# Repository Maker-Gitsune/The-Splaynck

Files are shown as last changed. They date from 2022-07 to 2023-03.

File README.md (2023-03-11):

# The Splaynck
My first foray into the world of mechanical keyboards.
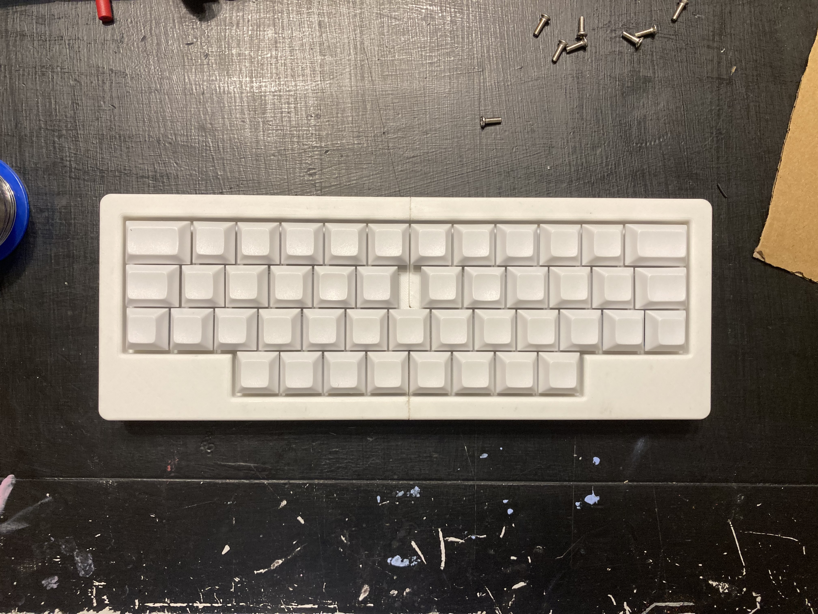
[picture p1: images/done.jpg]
the finished keyboard

# What is it?
banana for scale
- A compact, ergonomic keyboard for a lowish price. (~$50. including components in bulk, about $73 excluding filament.)
- Powered by [KMK](https://github.com/KMKfw/kmk_firmware) and compatible with [Peg](https://peg.software/)
- inspired by the Katana60 and the SICK-68.
# When is it?
- Now.
  - *Starting now. Total time is ~25 hours: ~16h printing, ~8 soldering (at least for me).
# Why is it?
- A ortholinear/grid layout is the most efficient in terms of space, but forces the wrists to bend outwards (uncomfortable).
- Splaying the rows outwards encourages neutral/reduced wrist angle which is more comfortable.
# How?
- The case is 3d printed and electronics are handwired/soldered.
- Everything else can be from Amazon.
- The parts I used/were bought (prices at time of purchase): 
  - [Akko ocean blue switches](https://www.amazon.com/dp/B08XX7TTZB/) - $14
    - 45x of any Cherry MX compatable switch will work.
  - [1N4148 diodes](https://www.amazon.com/dp/B06XB1R2NK) - $5
  - [Raspberry Pi Pico](https://www.amazon.com/dp/B08TVF499B/) - $8
  - [28 AWG wire](https://www.amazon.com/dp/B01F8PO7UK/) - $6
  - [M3 threaded inserts](https://www.amazon.com/dp/B09MCW7ZN5/) - $8
  - [M3x8 FHCS](https://www.amazon.com/dp/B01D4VHJJ6/) - $7.58
  - [YMDK DSA blanks](https://amazon.com/dp/B08YR6KNX9/) - $23
    - exact keycap sizes used:
      | size | Quantity |
      | ------------- | ------------- |
      | 1u    | 41 |
      | 1.25u | 2  |
      | 1.5u  | 2  |
    - It is possible to use all 1u keycaps. Just print the top pieces with "ortho" in the file names.

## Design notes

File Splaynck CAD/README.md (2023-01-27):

# Part orientation/print settings
## Pi Pico holder
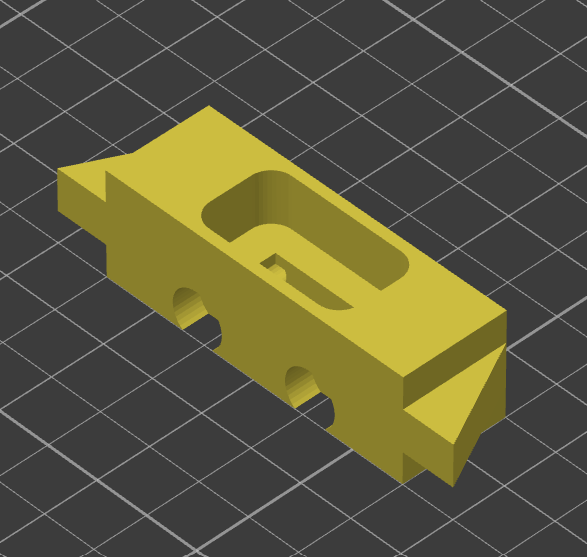
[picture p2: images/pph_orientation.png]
pph orientation

- The rectangle with rounded corners needs to face upwards.
- 3 walls, 3 perimeters, no more than 15% infill, supports enabled.
## Pins
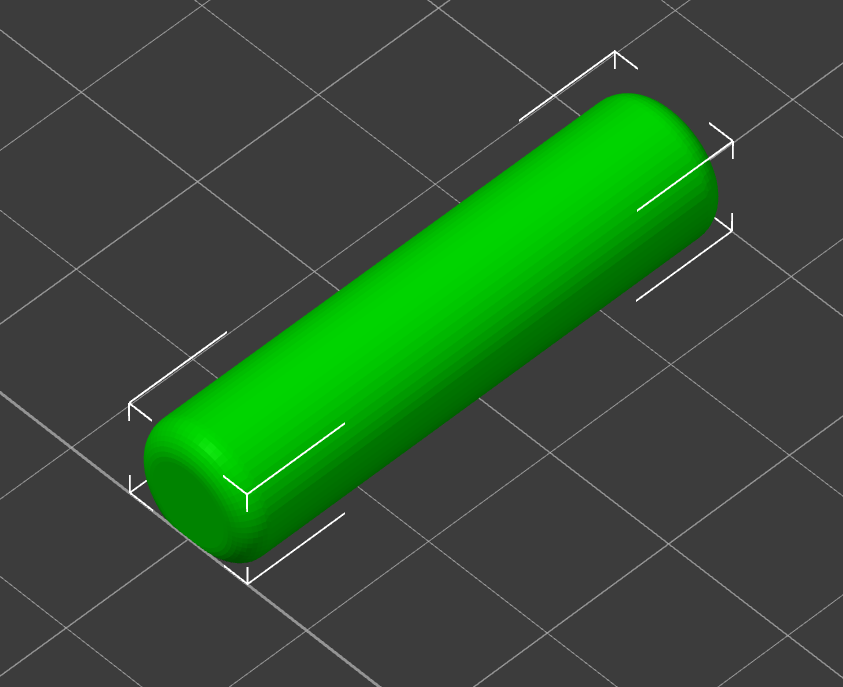
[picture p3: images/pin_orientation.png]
pin orientation

- Print flat side down.
- 3 walls, 2 perimeters, no more than 10% infill
## Tops and bottoms
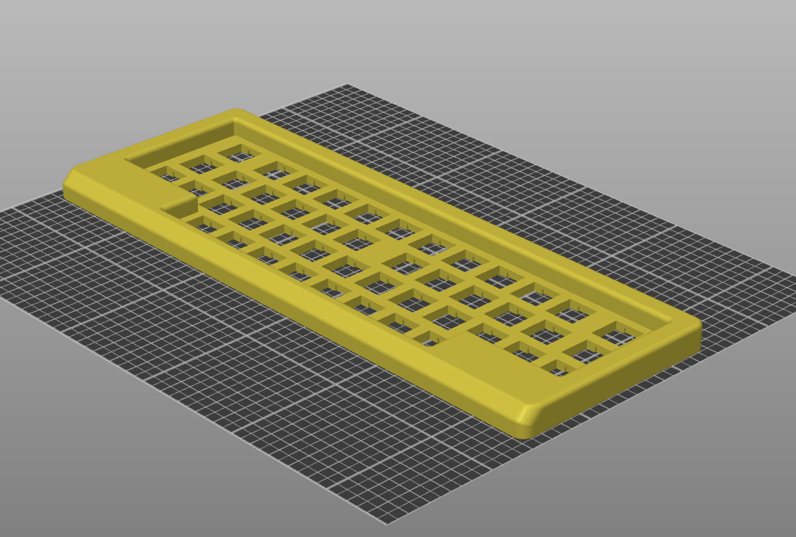
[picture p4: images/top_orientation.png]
top orientation

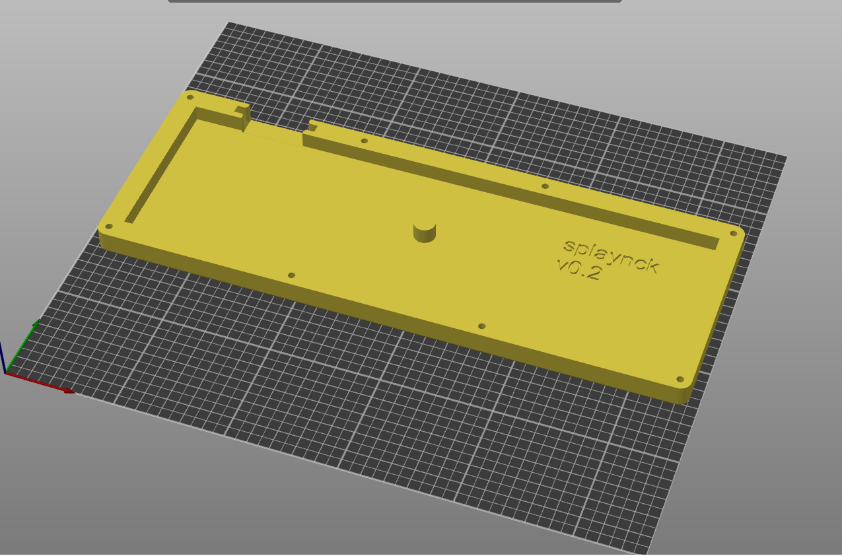
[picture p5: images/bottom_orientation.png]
bottom orientation

- print with largest face down.
- 3 walls, 3 perimeters, no more than 15% infill.

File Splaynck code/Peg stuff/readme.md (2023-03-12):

**IMPORTANT**

Currently, Peg appears to support a limited number of modules/extensions; If you are considering this, reference the Peg-specific main.py to see which are supported.

The code provided is the bare minimum needed to use Peg. If you choose this option, you will need to configure the keymap yourself.

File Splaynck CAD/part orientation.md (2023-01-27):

#Part orientation
- Pi Pico holder
  - The rectangle with rounded corners needs to face upwards.
- Pins
  - Print flat side down.
- Tops and bottoms
  - print with largest face down

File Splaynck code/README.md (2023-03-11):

# Keymap of the provided firmware
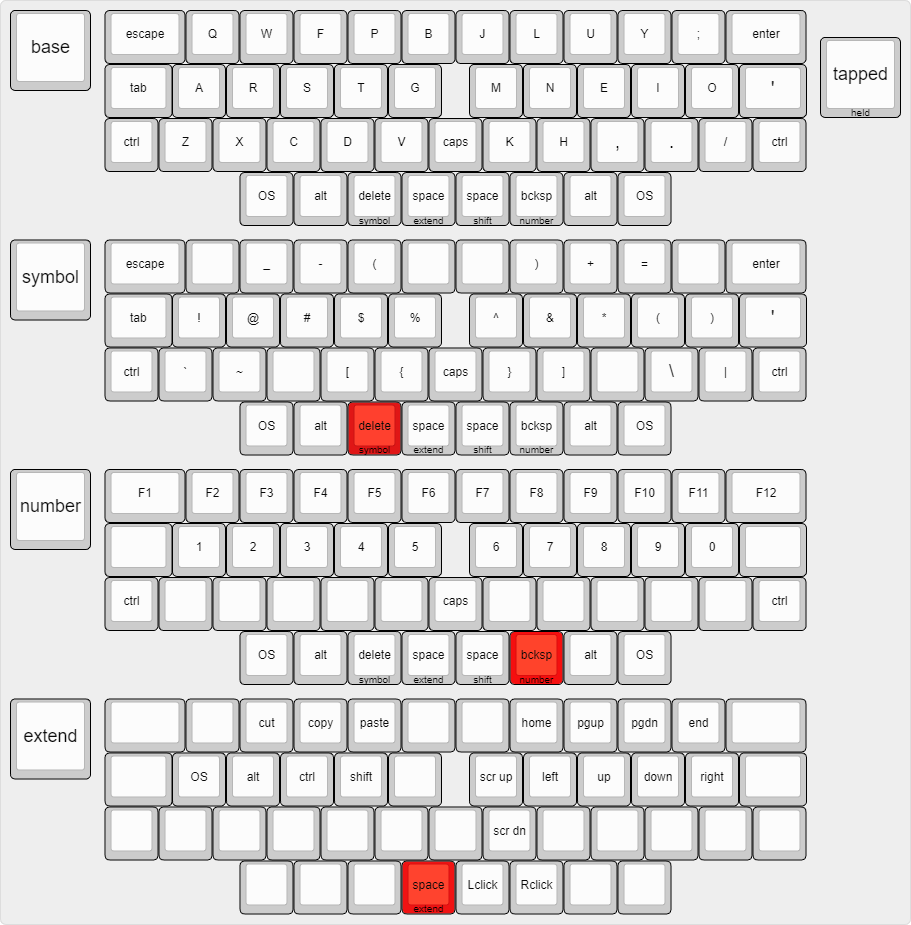
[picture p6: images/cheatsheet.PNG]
keymap


The following chords are not pictured, but are enabled by default:
- W and F send "wh"
- F and P send "ph"
- C and D send "ch"
- G and T send "gh"
- S and the left spacebar send "sh"
- T and the left spacebar send "th"
- Q and the left spacebar send "q"
    - also, "Q" sends "qu"
# Peg support (added 03/11/2023)
**IMPORTANT**
 - Currently, Peg appears to support a limited number of modules/extensions; If you are considering this, reference the Peg-specific main.py to see which are supported.

The code provided is the bare minimum needed to use Peg. If you choose this option, you will need to configure the keymap yourself.

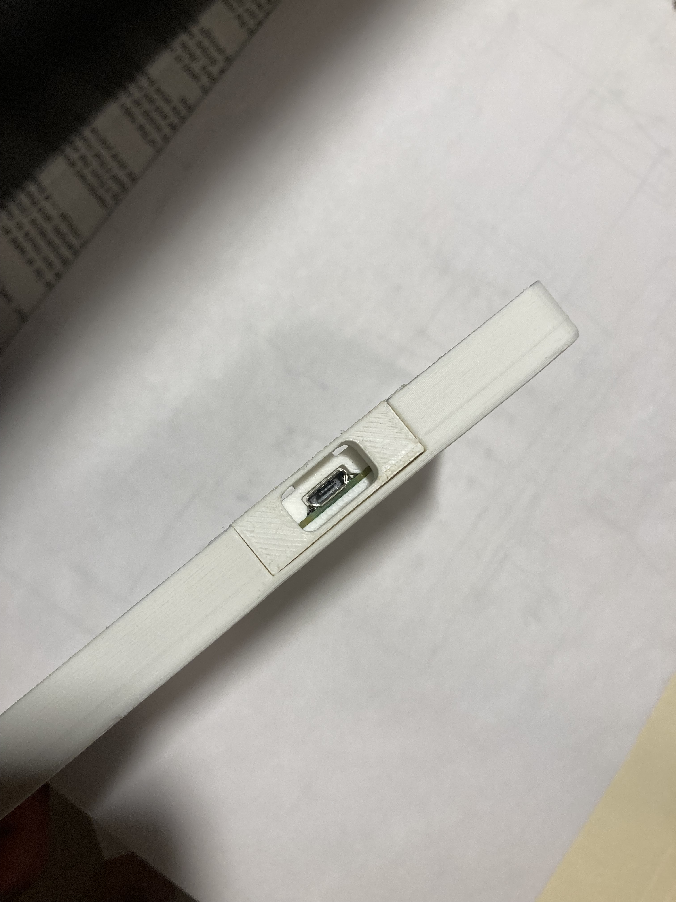
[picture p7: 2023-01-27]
images/pico_usb_port.jpg

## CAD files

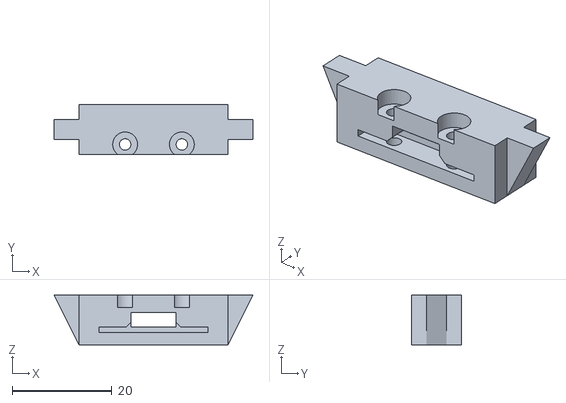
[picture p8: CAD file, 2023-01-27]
Splaynck CAD/pi pico holder.stl
40.0 x 10.0 x 10.0

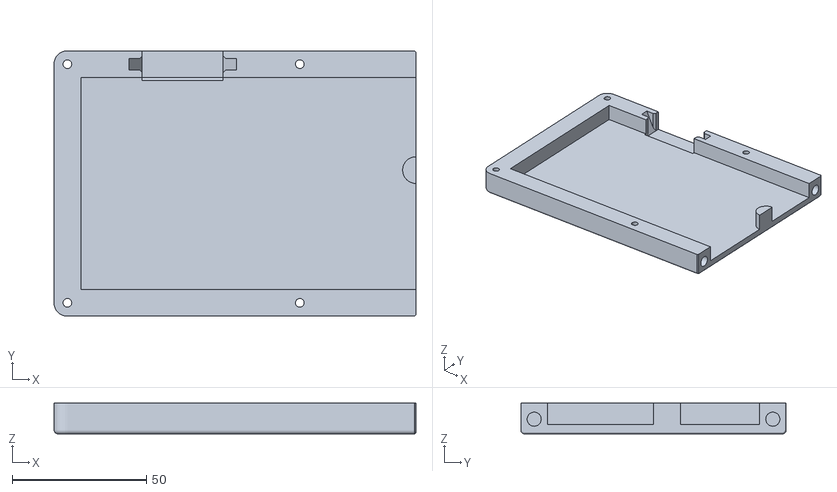
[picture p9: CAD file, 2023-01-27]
Splaynck CAD/splaynck_bottom/splaynck bottom_l.stl
135.0 x 99.0 x 11.5

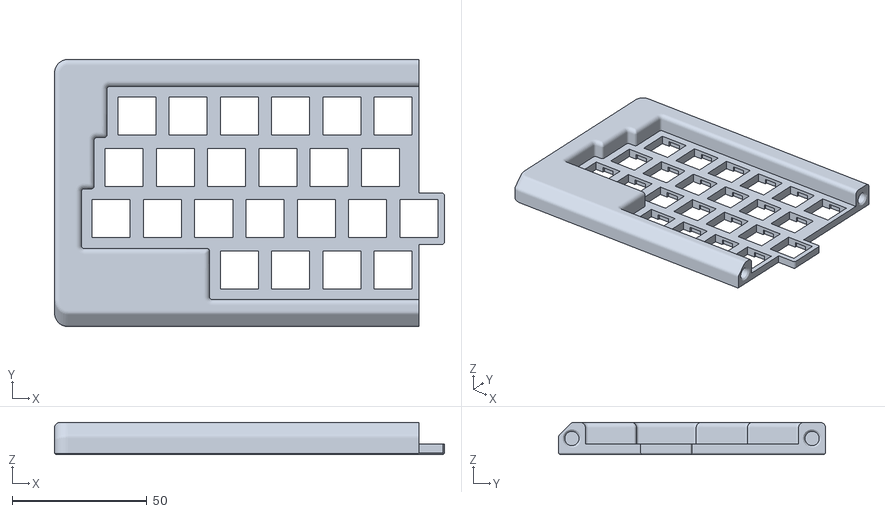
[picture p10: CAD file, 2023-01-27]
Splaynck CAD/splaynck_top/splaynck_ortho_top_l.stl
144.5 x 99.0 x 12.0

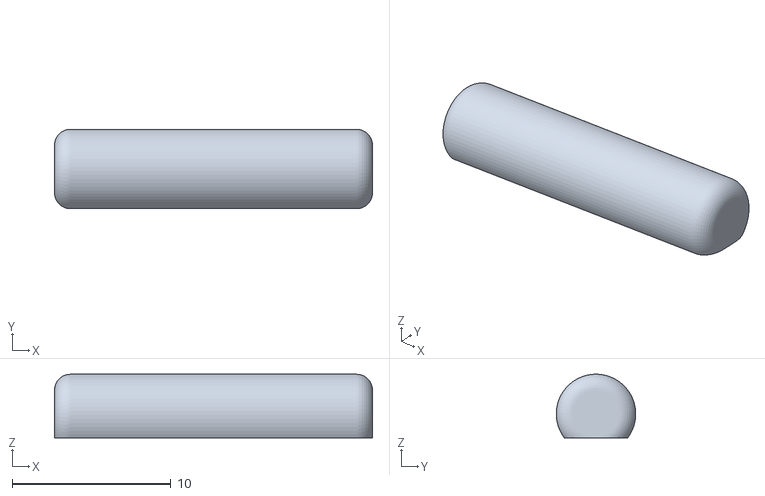
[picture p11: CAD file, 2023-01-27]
Splaynck CAD/splaynck pin.stl
20.0 x 5.00 x 4.00

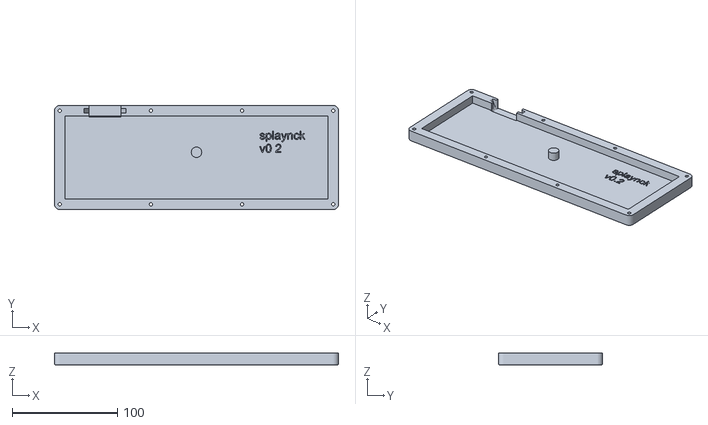
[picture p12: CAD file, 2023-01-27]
Splaynck CAD/splaynck_bottom/splaynck bottom.stl
270.0 x 99.0 x 11.5

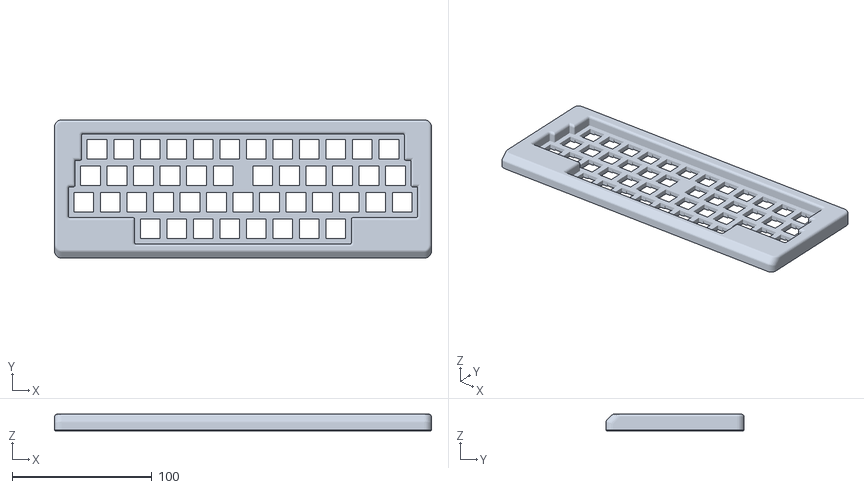
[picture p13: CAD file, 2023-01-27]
Splaynck CAD/splaynck_top/splaynck_ortho_top.stl
270.0 x 99.0 x 12.0

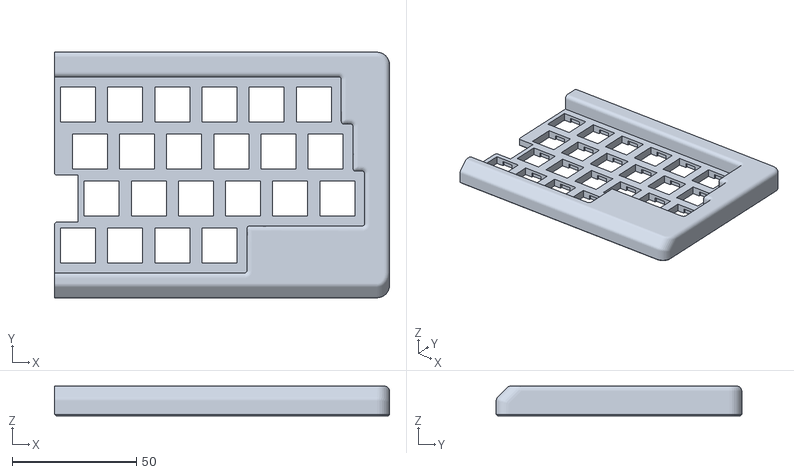
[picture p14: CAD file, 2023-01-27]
Splaynck CAD/splaynck_top/splaynck_ortho_top_r.stl
135.0 x 99.0 x 12.0

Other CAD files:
Splaynck CAD/splaynck_top/splaynck_HHKB_top_l.stl
Splaynck CAD/splaynck_bottom/splaynck bottom_r.stl
Splaynck CAD/splaynck_top/splaynck_HHKB_top_r.stl
Splaynck CAD/splaynck_top/splaynck_HHKB_top.stl

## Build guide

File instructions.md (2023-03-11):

# Prerequisites
- You know how to solder.
- You have installed [Peg](https://peg.software/) if you plan to use it.
# Parts needed
- 45 Cherry MX or compatible switches
- 1N4148 diodes
- Raspberry Pi Pico
- 28 AWG wire
- M3 threaded inserts
- M3x8 FHCS
- A micro USB cable (I used an old phone charger)
- Keycaps
    - exact keycap sizes used:
      | size | Quantity |
      | ------------- | ------------- |
      | 1u    | 41 |
      | 1.25u | 2  |
      | 1.5u  | 2  |
    - It is possible to use all 1u keycaps. Just print the top pieces with "ortho" in the file names.

# Instructions
1. Print one of “top” and “bottom” and the pi pico holder.
    - If you have a smaller print bed (less than 280mm x/y, but equal to or larger than 150mm x/y), print one of top_l, top_r, bottom_l, bottom_r, in addition to 4x pins instead of "top" and "bottom"
    - There are two variations of the top: one with a HHKB-inspired layout and one that is for ortholinear (all 1u) keycap sets.
2. If you haven't, set up and test [KMK](https://github.com/KMKfw/kmk_firmware/blob/master/docs/Getting_Started.md) on the Raspberry Pi Pico you intend to use. Also, make sure your computer has a text editor that supports circuitpython with a serial window. I used [Mu](https://codewith.mu/).
3. If applicable, glue top_l, to top_r, and bottom_l to bottom_r together using the pins.
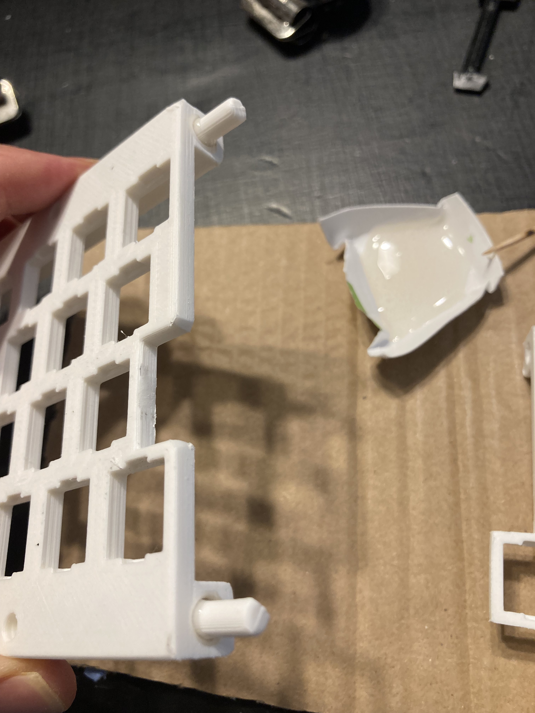
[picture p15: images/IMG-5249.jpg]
pin detail

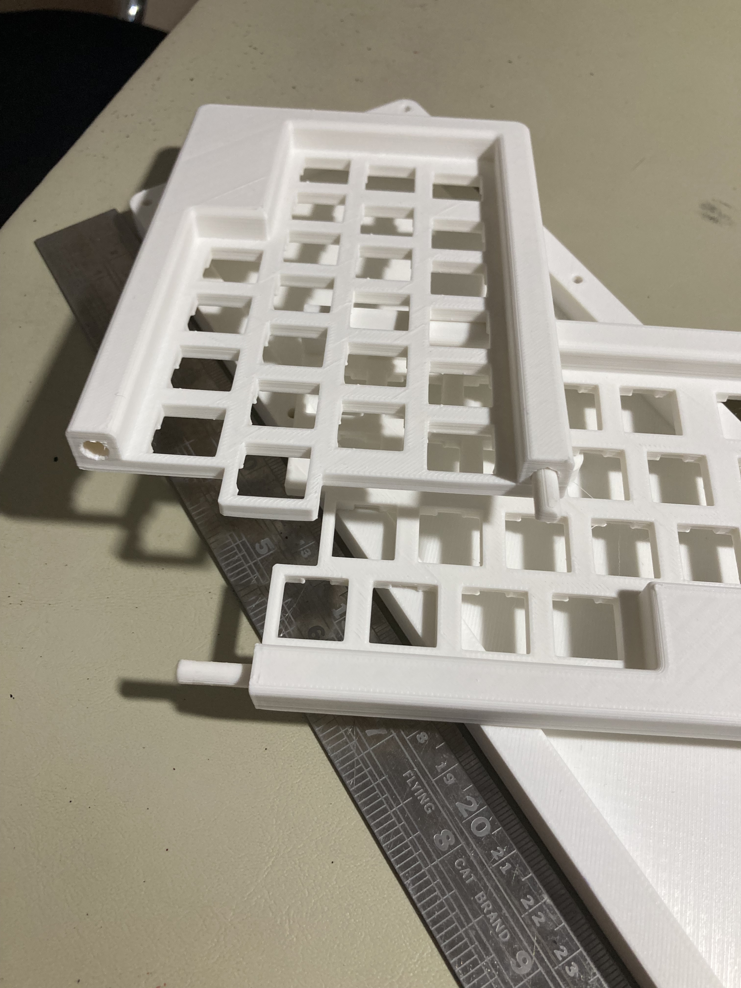
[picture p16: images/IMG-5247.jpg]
pin detail again
 
    - Sanding where the parts come together is recommended for fit and bond strength.
    - If needed, use a box cutter to deburr the holes/edges.
    - Feel free to sand the outside once the glue is cured.
4. Add heat set inserts to the 8 holes in “top”
5. Install switches with the LED slots at the bottom
6. insert the Pi Pico into the holder, and the holder into the bottom. Note that the Pi Pico will only go in one way.
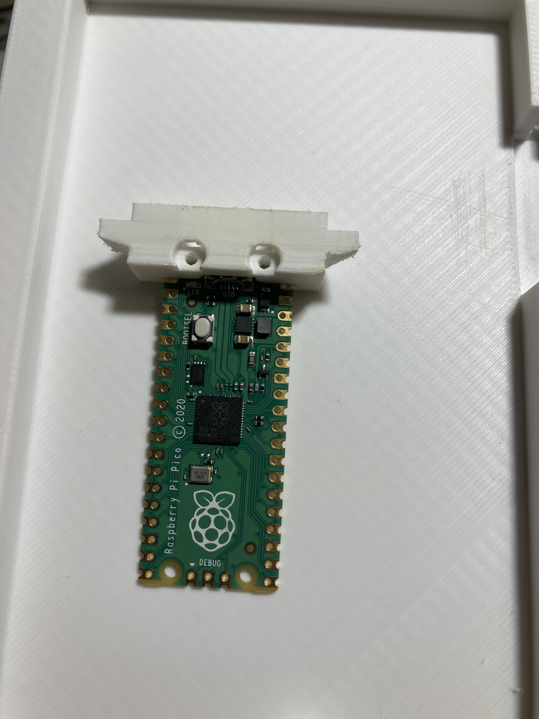
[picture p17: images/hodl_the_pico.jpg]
pico holder

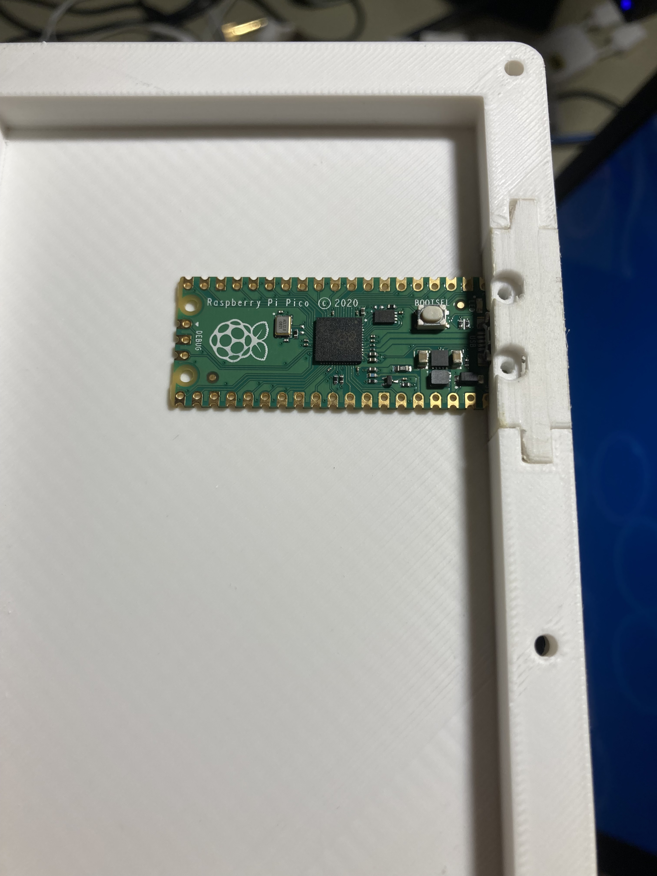
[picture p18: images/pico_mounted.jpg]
mounted

    - It is optional, but hightly reccomended that the Pi Pico is fastened to the insert by the use of pins made of short lengths of 1.75mm filament. You will likely need to ream the holes in the holder with a 2mm drill bit before the filament will fit. Make sure that the filament is cut flush with the top of the holder.
    - The bottom corners will likely need some sanding.
7. Handwire according to the pictures below. Make sure the wires are long enough to reach the pi when both halves' front halves when they are touching.
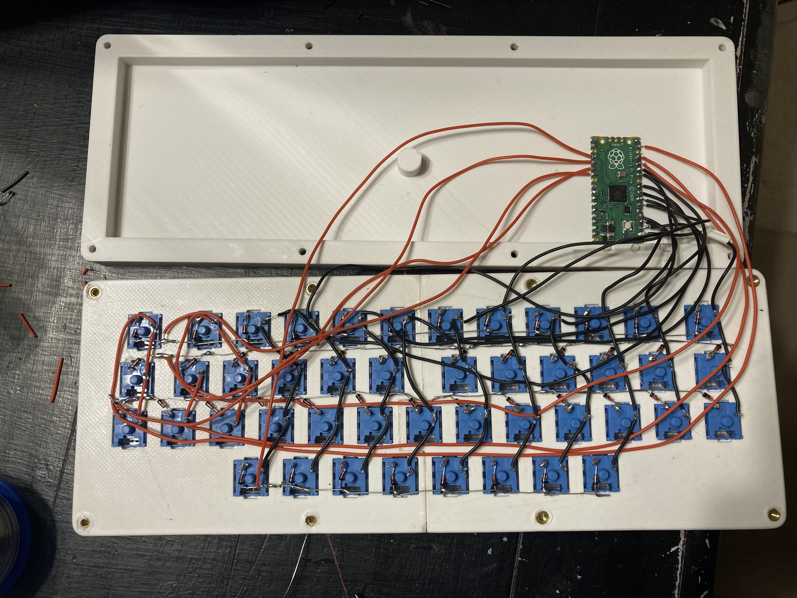
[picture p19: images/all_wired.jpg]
wiring

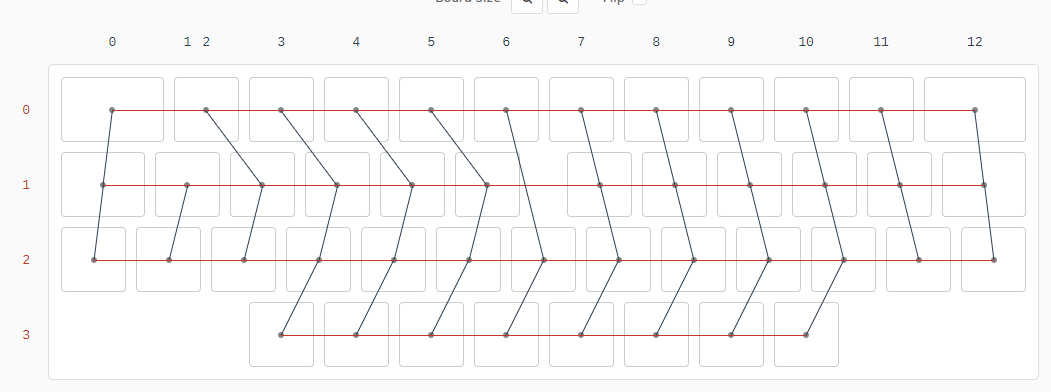
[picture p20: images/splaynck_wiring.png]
wiring diagram

    - **each switch needs to have a diode that points towards the rows**
    - **Note that the wiring in the middle of the second to topmost row is bent to clear the support in the bottom half of the case**
pico pinout
    - from left to right, the columns are wired to the pico on pins **GP14 to GP2**
    - from top to bottom, the rows are wired to the pico on pins **GP21 to GP18**
8. Load the firmware.
    - For normal KMK usage:
        - Transfer all the files from "Splaynck Code" (except for the readme) to the pi pico. Test the keyboard while everything is acessible.
        - **Make sure that "old main.py" is renamed to "main.py" or "code.py"**
        - The default layout is Colemak-DH. If you use another layout or want to modify any of the layers, now is the time to do it.
        - boot.py hides the Pi Pico's drive unless the upper leftmost key is held when plugged in. You do not need to have this, but it is reccomended to make sure that the keyboard will immediately work when plugged in.
    - For Boardsource's Peg remapping tool:
        - Transfer all the files from "Peg stuff" to the pi pico.
        - Launch Peg.
        - setup your keymap and test.
9. assemble and add the keycaps
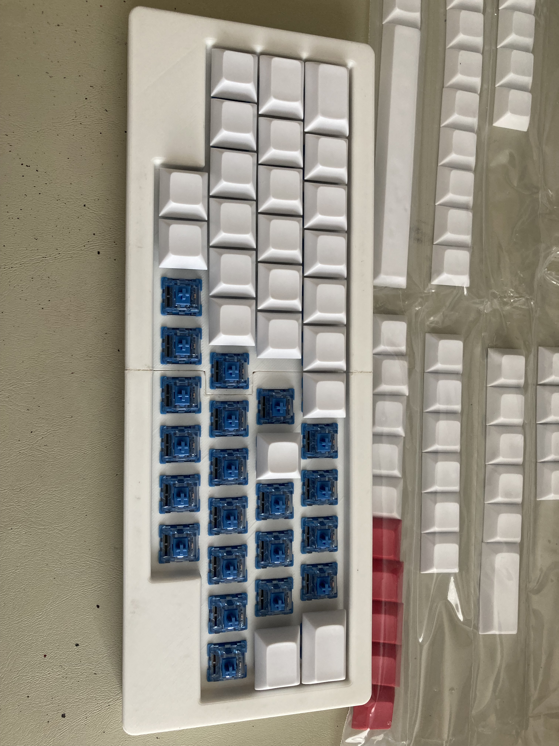
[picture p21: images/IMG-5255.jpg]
nearly finished

    - be careful when closing the upper and lower halves. Take time to nudge the wires into the case before tightening the screws. **Do not overtighten**    
10. Familiarize yourself with the key arrangement.
    - Here are some websites that I have used for typing practice:
        - https://gnusenpai.net/colemakclub/
            - Use the ortho setting
        - https://keybr.com/

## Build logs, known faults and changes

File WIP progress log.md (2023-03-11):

# CAD/Build/Progress log (this itself is not finished.)
## V0.0 - Minimum Viable-45
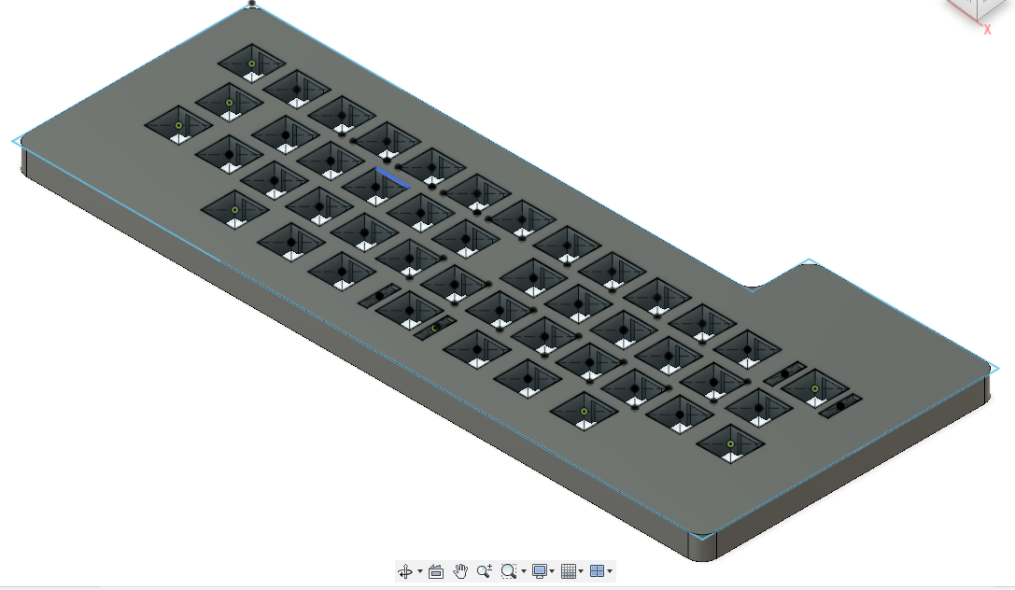
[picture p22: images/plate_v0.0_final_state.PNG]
V0.0

- 45 keys
- Designed around normal keycap sizes
- Thicc plate - 10mm
- Progressed only to first extrusion/switch cutouts
## V0.1 - the Splaynck (splay+planck)
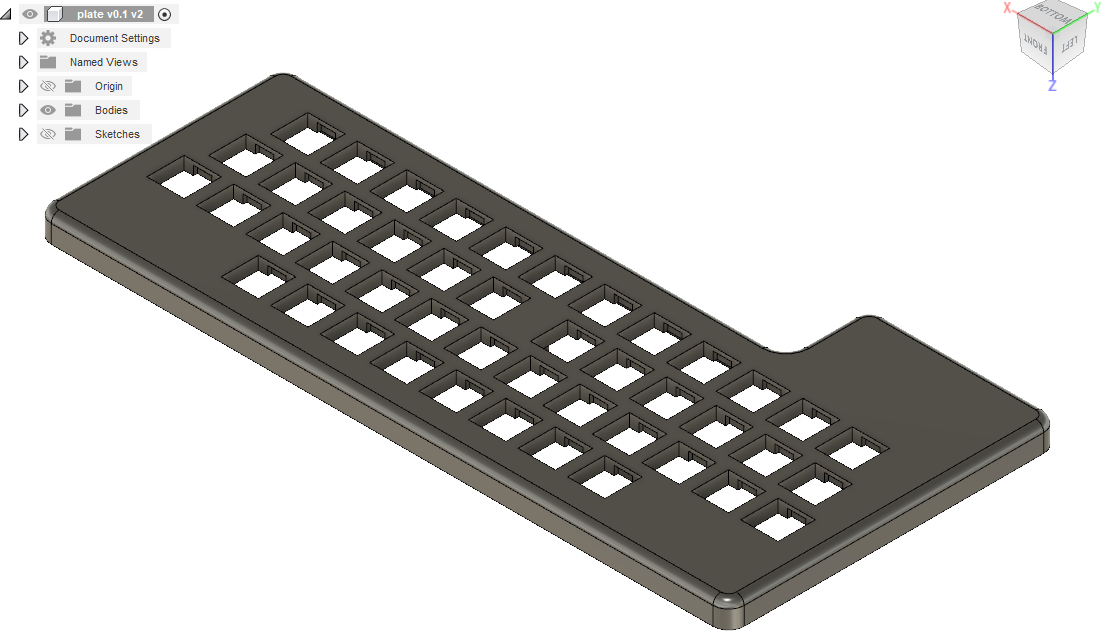
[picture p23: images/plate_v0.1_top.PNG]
V0.1 top

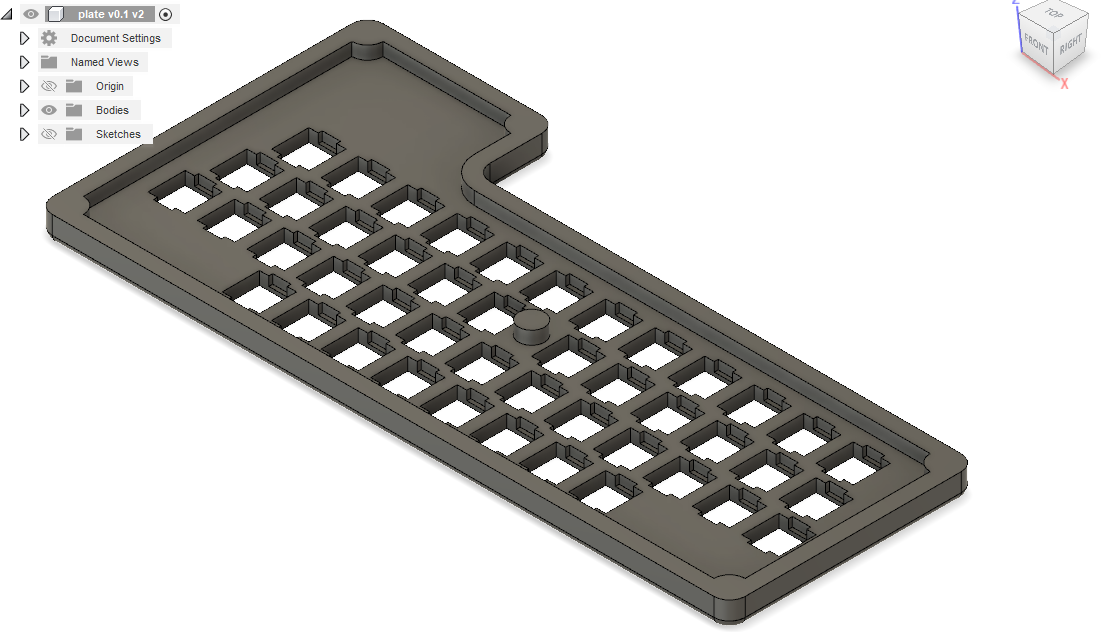
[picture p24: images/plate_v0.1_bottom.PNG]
V0.1 bottom

- 45 keys (spacebar will be 2x1u)
- Designed around planck/ortho sets
### Notes
- Adopted for smaller overall size - 266mm wide. It can theoretically be printed in one piece.
- No stabilizers, no stabilizer problems
### Log
#### 05/29/2022 
- Plate mostly done - switch cutouts and relief cuts.
- I would like to have parts in hand to test the following
    - switch fit
    - Threaded insert holes
    - Controller mount
- To do 
- Holes for threaded inserts
- Pi Pico mount
- Bottom plate - should be the simplest part
## V0.2 - It’s time to stop ok? no more
### Notes
- SICK-68 style construction
- I should probably just finish one to test layout/preliminary feel before changing more things.
    - As of 06.20.22, I deny the existence of the me who typed the above.
- Addition of pseudo HHKB variant
- Designed for blank uniform profile sets
- Microcontroller sled/cartridge
    - Interference fit
    - Compatible with 
        - Pi pico
        - Pro micro (scrapped)
- Dimensions
    - Sub 16mm height from tabletop to top of plate
    - 10x8mm bezel
    - 2mm clearance between keycap and bezel
    - 5x20mm dowel pins with squared bottom
### Log
#### 06.20.22 - 2h
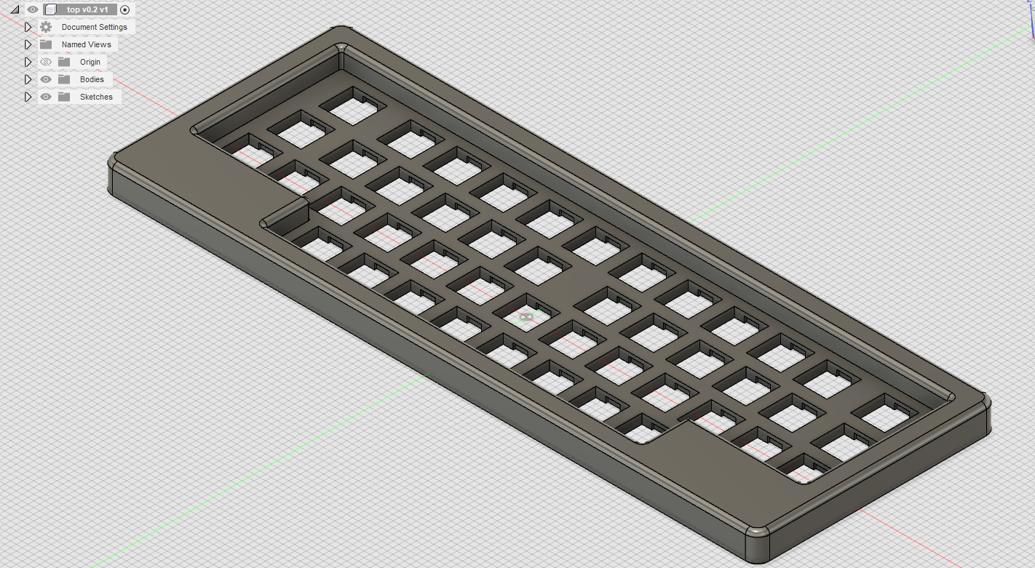
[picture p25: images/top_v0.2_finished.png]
V0.2 top

- It’s time to stop. No more revisions
- Stuff to do 
    - bottom
    - Micrcontroller sled, slot
    - Insert holes
    - Confirm switch tolerances
#### 06.21.22 - 1h
- Bottom done, sled started
- Stuff to do 
    - Ortho top
    - Finish microcontroller sled, slot
    - Insert holes
    - Confirm switch tolerances and center distance
    - Test fit sled and mockup of slot
#### 06.30.22 - 3h
- Parts are here. Switch fit evaluation. 
- Observations
    - Relief cuts can now be 16*5mm
    - 14.1mm ^2 for switch fit
    - Bezel changed from 10*6 to 10*8
- Stuff to do
    - Ortho top
    - Finish microcontroller sled, slot
    - Insert holes
    - Test fit sled and mockup of slot
#### 07.01.22 - 1.5h
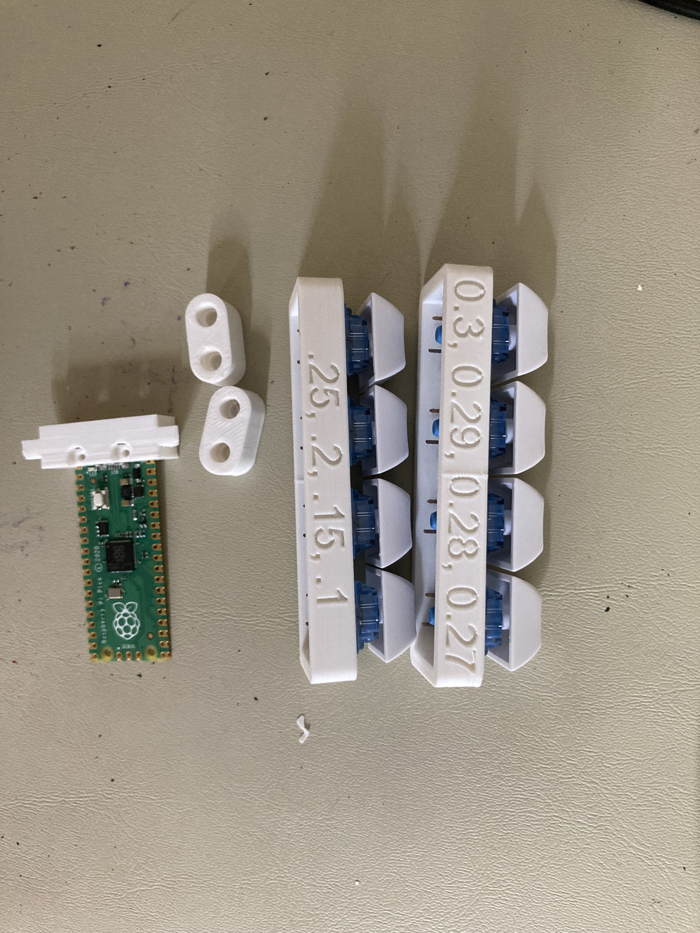
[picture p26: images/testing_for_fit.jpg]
testing

- More testing
- Threaded insert holes - 5*5mm, 1mm chamfer around the opening
- Stuff to do
    - Ortho top
    - Insert holes
#### 07.02.22 - 2h
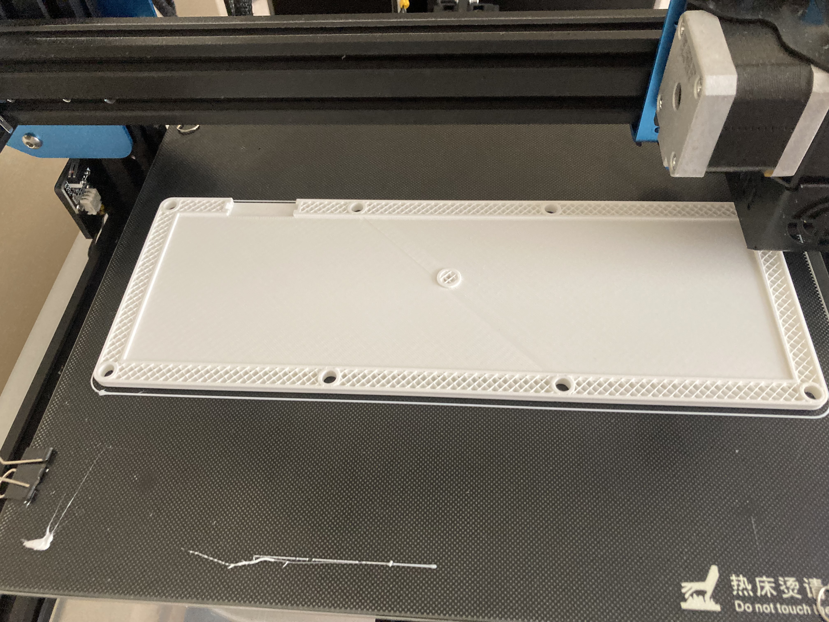
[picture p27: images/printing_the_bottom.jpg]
printing the bottom

 - It begins…
 - Threaded insert testing finished.
 - Bottom printed
 - Programing started: system details
 - Stuff to do
    - Ortho top
#### 07.03.22 - 1h
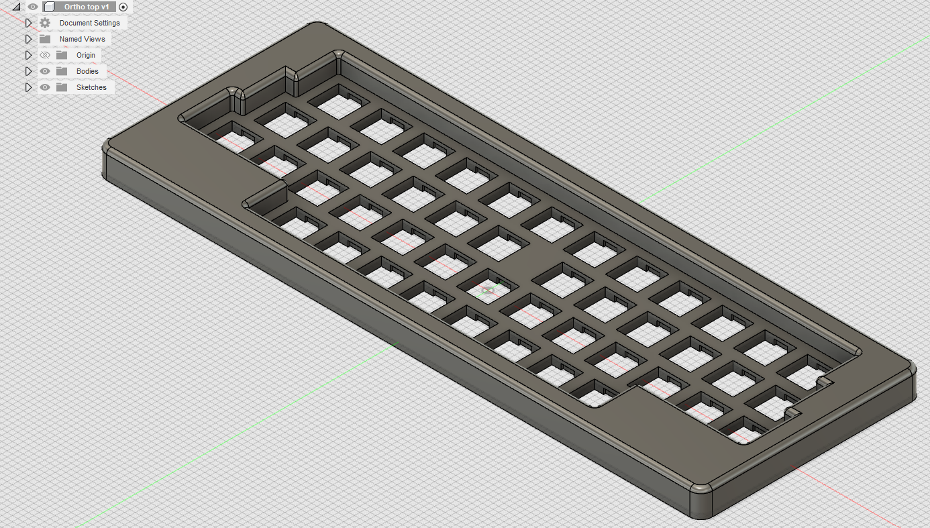
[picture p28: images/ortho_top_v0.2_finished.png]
Ortho top

- Top left printed
- Ortho top finished
- Split version complete
- CAD is finished
#### 07.04.22 - 2.5h
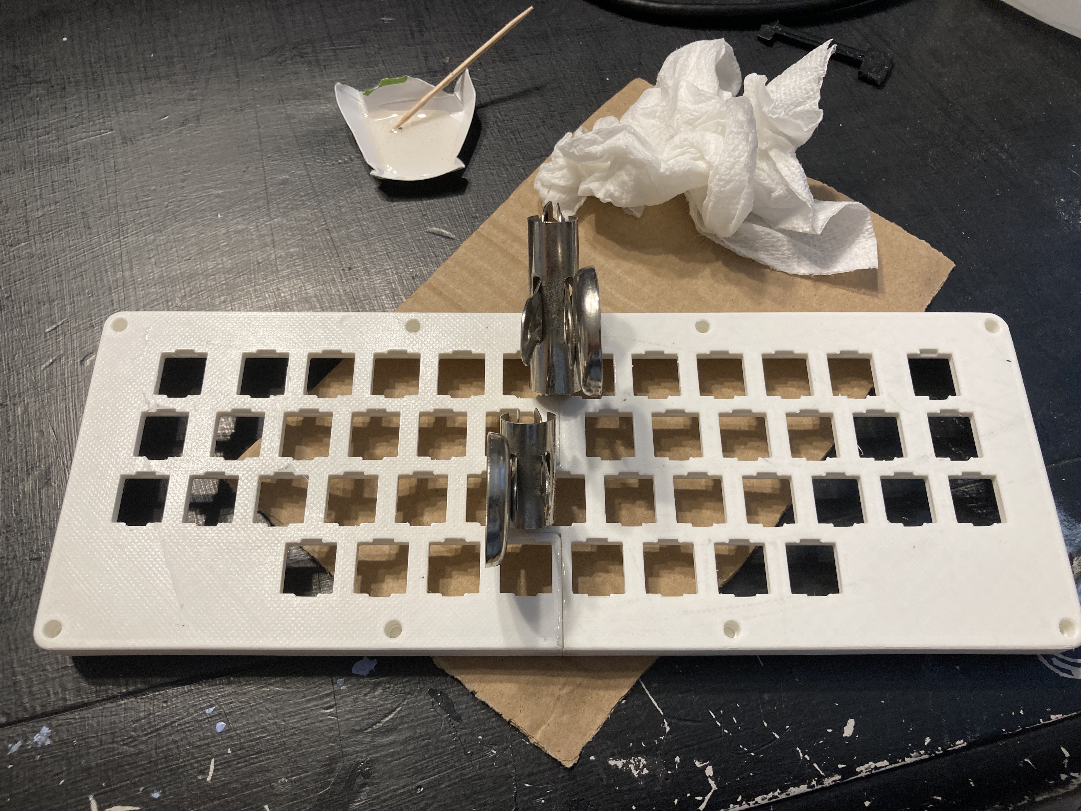
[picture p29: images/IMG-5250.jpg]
gluing

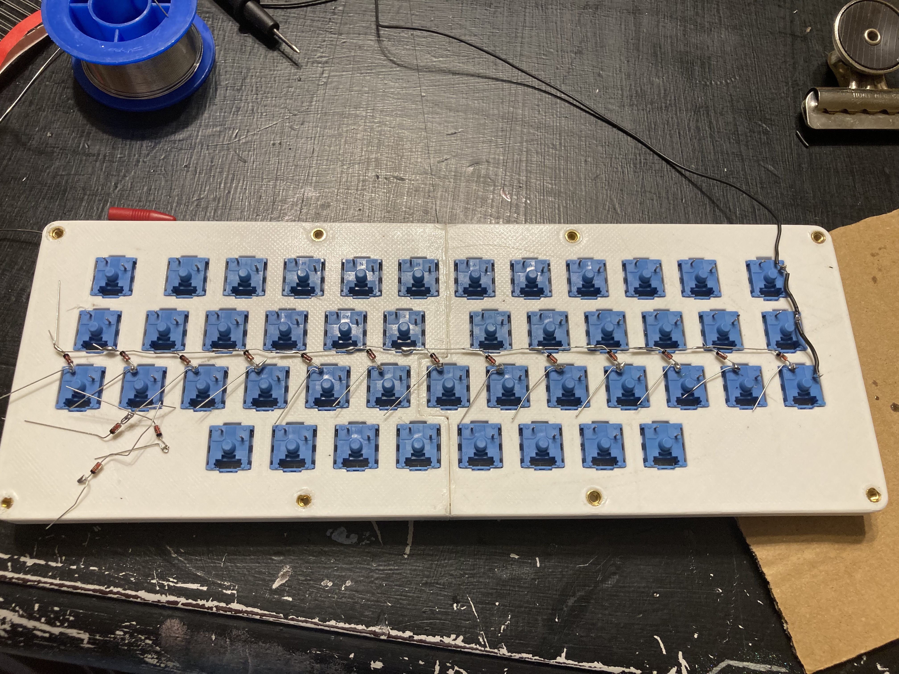
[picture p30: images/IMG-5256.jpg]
the start of wiring

- Top left printed. Top pieces are sanded to fit and epoxy-ed together
- Threaded inserts installed. Soldering started. Row 2 done.
#### 07.05.22 - 2h
- Rows completed. Columns started
#### 07.06.22 - 1h
- To column 6
#### 07.07.22 - 3h
wiring
wiring
- Wiring finished
#### 07.08.22
- Programming started
#### 07.09.22
- Changed to consolas font. 
- Attempted coordinate mapping
#### 07.14.22
- It functions
- Base, mouse and number layers completed
#### 07.17.22
- Symbol and system layers finished
#### 01.27.23
- I added a chamfer to the front of the top pieces in CAD.
#### 03.11.23
- I have implemented support for Boardsource's Peg remapping tool. It appears to work to the full extent of it's abilities.

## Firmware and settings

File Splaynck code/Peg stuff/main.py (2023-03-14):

from kb import KMKKeyboard
from kmk.keys import KC
from kmk.modules.layers import Layers
from kmk.modules.modtap import ModTap
from kmk.hid import HIDModes
from kmk.handlers.sequences import send_string
import supervisor
keyboard = KMKKeyboard()
modtap = ModTap()
layers_ext = Layers()
keyboard.modules.append(layers_ext)
keyboard.modules.append(modtap)
keyboard.modules = [layers_ext, modtap]
# keymap
keyboard.keymap = [ [KC.ESCAPE,KC.Y,KC.P,KC.O,KC.U,KC.J,KC.K,KC.D,KC.L,KC.C,KC.W,KC.ENTER,KC.TAB,KC.I,KC.N,KC.E,KC.A,KC.COMMA,KC.M,KC.H,KC.T,KC.S,KC.R,KC.TAB,KC.CAPSLOCK,KC.Q,KC.Z,KC.SLASH,KC.DOT,KC.SCOLON,KC.F5,KC.B,KC.F,KC.G,KC.V,KC.X,KC.NO,KC.LGUI,KC.LALT,KC.DELETE,KC.RSHIFT,KC.SPC,KC.BSPC,KC.RALT,KC.RGUI], 
[], 
[], 
[], 
[], 
[], 
[], 
[] ] 
# keymap
if __name__ == '__main__': 
    keyboard.go(hid_type=HIDModes.USB)

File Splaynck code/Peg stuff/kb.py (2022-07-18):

import board

from kmk.kmk_keyboard import KMKKeyboard as _KMKKeyboard
from kmk.scanners import DiodeOrientation

class KMKKeyboard(_KMKKeyboard):
    col_pins = (
        board.GP2,
        board.GP3,
        board.GP4,
        board.GP5,
        board.GP6,
        board.GP7,
        board.GP8,
        board.GP9,
        board.GP10,
        board.GP11,
        board.GP12,
        board.GP13,
        board.GP14,
    )
    row_pins = (
        board.GP21,
        board.GP20,
        board.GP19,
        board.GP18,
    )
    diode_orientation = DiodeOrientation.COLUMNS

    coord_mapping = [
     0,  1,  2,  3,  4,  5,  6,  7,  8,  9, 10,     12,
    13, 14, 15, 16, 17, 18,     20, 21, 22, 23, 24, 25,
    26, 27, 28, 29, 30, 31, 32, 33, 34, 35, 36, 37, 38,
            41, 42, 43, 44, 45, 46, 47, 48,
    ]
